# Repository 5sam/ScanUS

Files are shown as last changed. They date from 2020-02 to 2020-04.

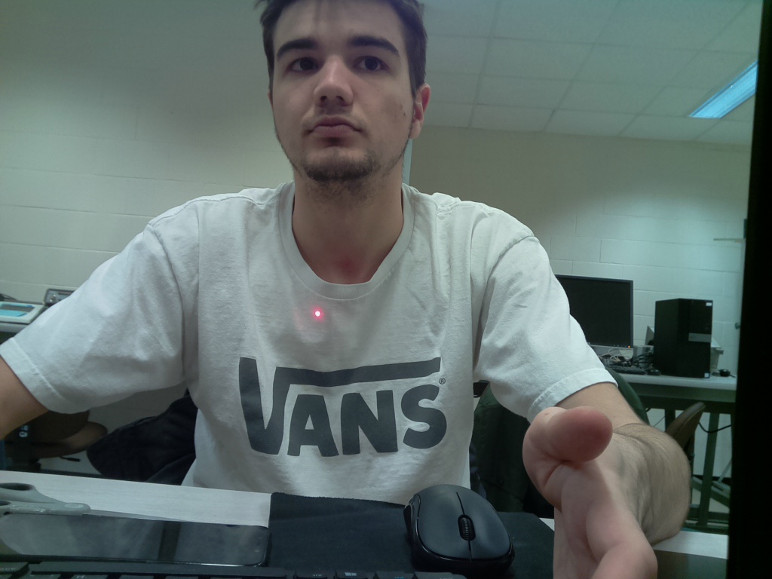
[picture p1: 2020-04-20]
test.jpg

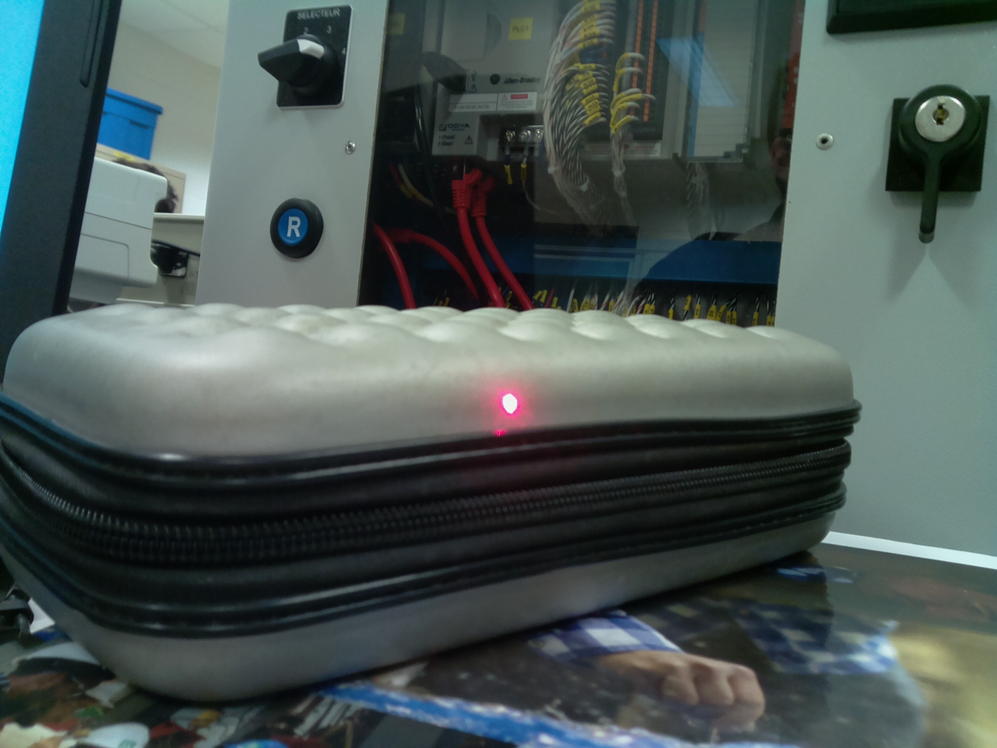
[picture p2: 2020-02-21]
Images/pi_test_proche.jpg

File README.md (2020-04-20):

# ScanUS
4th semester project of Robotics Engineering at **Université de Sherbrooke**

This project is a simple and cheap solution to 3D scanning
## Calibration
### Intrinsic Parameters
- To calibrate the intrinsic parameters of your Picamera, you should take at least 20-30 pictures of a calibration grid
- Chessboard calibration grid patterns can be found [here](https://markhedleyjones.com/projects/calibration-checkerboard-collection)
- The parameters of the chosen grid can be set in the calibration.py header or can be inputs when you call calib_camera()
- The outputed values of **mtx** and **dist** should then be written in the header of camera.py
### Extrinsic Parameters
- To calibrate the extrinsic parameters of the camera, use calib_camera_ext() with a picture containing known positions in world
- Enter known points in points_in_world array
- Locate points in the same order using the zooming option if necessary (using **z** key)
- Double-click to save point
- Once all points are saved press **esc** to exit and plug the output to CAMERA_POS in camera.py if the error is acceptable
- If the error is unacceptable, repeat this process with more known points

### Note
- The camera must have its y axis pointing towards the center of the image when calculating the **CAMERA_POS** and **CAMERA_ANGLES** 

## Setting up the Pi
### Material needed:
- A Raspberry Pi 3B/3B+
- A working internet connection
- A fan

### Note: 
OpenCV is the library that allows the image analysis portion of the software. 
However, installation on the Raspberry Pi as of 2020/02/25 is difficult due to there not being
precompiled binaries in PyPi. 
An Pi image with a compiled version of OpenCV was included to make the installation easier for future users. 
The manual compilation will be explained further bellow. 

### Recommended installation:
1. Download the image of the Pi contained in the [link](currently missing:we did not find a good way to share 32Gb)
2. Install BalenaEtcher to flash the image to your microSD card.
3. All of the libraries used will already be installed. So the installation is now complete.
4. To use the virtual environment. Type the following commands into the terminal:
- source ~/.profile
- workon cv 
5. If you see (cv) on the command line. You are now working on the virtual environment set up to work with openCV. 
6. Head to your project directory and run your code by calling your main:
python file_name.py
7. If done correctly. The libraries should be accessible and the code should run without a hastle.

### Manual installation:
1. Start by opening a terminal.
2. Check if a compiled binary exists by typing:
sudo pip install opencv-contrib-python
If there installation begins. SKIP to step 6.
2. To manually install/compile OpenCV an internet guide will be used with a few changes. Note that any 
version can be installed. The guide installs version 4.0.0 but we installed the lastest version as of today (4.2.0).
3. The guide can be found [here](https://www.pyimagesearch.com/2018/09/26/install-opencv-4-on-your-raspberry-pi/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)
4. First change to be aware of. make -j4 command should be used as stated in the guide. Be careful, our Pi
3B+ managed to overheat during the installation despite having a heatsink. If you have a fan, make it blow air 
towards your Pi to keep it cool. It is possible for your Pi to shutdown or throttle if it is not cooled properly 
slowing down the installation. Despite the installation working well. Your Pi may hang due to a race condition 
towards the end. If so, press ctrl+C to terminate compilation (ours did around 80% and then around 98%). 
Don't worry, the files that are already compiled will not be compiled again. Then modify the command to: 
make -j1 
The compilation will be slower but will no longer hang indefinately in the critical sections. 
5. In step 6, make sure to browse your Pi's directory for the files mentionned. Your 
cv2.cpython-35m-arm-linux-gnueabihf.so and cv2.so files might be in different folders depending on your python
version and location of your python files inside your Pi. Search for them through your files and use the correct 
path to avoir errors in creating the link to your virtual environment.
6. With your environment set up. Open a terminal and call the following 2 commands:
source ~/.profile
workon cv
The first one allows you to use workon cv command to open the virtual environment set up with openCV in the current 
terminal. The second is the activation of the environment.
7. Many external libraries are used with this project. The following steps are necessary if they haven't yet been 
installed on your Pi. 
8. Open a terminal and open your virtual environment.
9. Go to your project's path and run the main with:
python main.py
10. If you get a message saying an import could not be found. Type the name of the library on google as follows:
"library_name pypi"
PyPI contains all the libraries used and will show the correct pip install command to download the latest version of
each library.

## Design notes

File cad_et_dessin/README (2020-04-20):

Bill of matérial are in the drawing of assembly of Full_model.
Model of standard part are found the on site of McMaster.
Counsult https://www.mcmaster.com/ for more information.

Assembly note :
Cad of the XM430-W350-R.step is used as standin for the XM430-W350-T and the XL430-W240-T. 
The XL430-W240-T is place at the base of the Rail. (see Lazer_stand.sldasm)
Full_model depict reasonnable distance for the laser and camera, adjust position on the base and in the code if needed.
Fix your open cr and Pi on the base if needed.
Verifie the  flange on your motor and adjust the configuration of connector if needed.
Laser_stand and turning_table may be placed on any surface, but we recommande fixing it to sheet of plywood 3/4

## 3D Printer Settings
  Each part was printed on a Creality Ender 3 and had different settings depending on the part.
  The software used to slice the parts is Ultimaker Cura 4.5 and prints were all made on standard quality.
  All supports are generated with the default overhang angle calculation from the software and all other settings
  are the ones by default.
  ### Mobile support
  - 20% infills
  - No Supports
  - Extruder temp: 200
  - Bed temp: 55
  ### Turntable Support
  - 20% infill
  - Supports on
  - Extruder temp: 200
  - Bed temp: 55
  ### Wheels
  - 20% infill
  - No Supports
  - Extruder temp: 200
  - Bed temp: 55
  ### Spacers
  - 50% infill
  - No Supports
  - Extruder temp: 200
  - Bed temp: 55
  ### Rail
  - 65% infill
  - Supports On
  - Extruder temp: 200
  - Bed temp: 55
  ### Connector Bolt
  - 35% infill
  - Supports On
  - Extruder temp: 200
  - Bed temp: 55
  - Bed plate adhesion: Brim (to reduce warping)
  ### Connector Motor
  - 35% infill
  - Supports On
  - Extruder temp: 200
  - Bed temp: 55
  - Bed plate adhesion: Brim (to reduce warping)
© 2020 GitHub, Inc.

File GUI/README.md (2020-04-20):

# gui.py
Contains the class Application used to generate the UI **Université de Sherbrooke**

## Code
### Common usage
- import tkinter as tk
- create an instance of tk.Tk() i.e.: your_instance=tk.Tk()
- Optionally, give the window a name using: your_instance.title('Your_title') 
- Create an instance of the user interface with gui_instance = gui.Application(master=your_instance)
## Functions

# def __init__(self, master=none):
- Constructor to create window and buttons for the gui
- Creates thread safe objets that are to be shares with other sections of code outside of UI
- Creates the thread to handle the window events

# def create_widgets(self, need_plot):
- Creates the different buttons including their positions and actions when pressed
- Receives the variable to be toggled by the checkbox 

# def set_running(self, value): 
- sets value of is_running to value using the lock to prevent issue with threads

# def get_running(self):
- returns value of is_running using the lock to prevent issue with threads

# def set_cancel(self, value):
- sets value of cancel to value using the lock to prevent issue with threads

# def get_cancel(self):
- returns value of canel using the lock to prevent issue with threads

# def get_need_plot(self):
- returns value of need plot using the lock to prevent issue with threads

# def toggle_var_plot(self):
- Changes value of plot from False to True according to it's previous value using the lock to prevent issues with threads

# def do_stop(self):
- Called by stop button
- Deactivates the stop button and activates the buttons start and cancel
- Sets is_running to false

# def do_start(self):
- Called by start button
- Deactivates the start button and activates the buttons stop and cancel
- Sets is_running to true and cancel to false 

# def do_cancel(self):
- Called by cancel button
- Deactivates the buttons cancel and stop (if necessary) and activates the start button
- Sets cancel to true

# def plot_change(self):
- Called when clicking the checkbox
- Toggles need_plot to the correct value according to the checkbox

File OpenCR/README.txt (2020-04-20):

- Follow the steps in this guide to properly set up your OpenCr:
	http://emanual.robotis.com/docs/en/software/dynamixel/dynamixel_workbench/

-Change the DXL_IDs in communication.ino to fit your motor, you can find them by using one of the tutorial's function
in the previously downloaded library called <Find>.

-Upload communication.ino on your OpenCr.

-Plug 2 motors directly into the Opencr (1 XM,it is going to be motor 1 and 1 XL, it is going to be motor 2) and one motor in serial with one that is plug into the OpenCr (motor 3)

-Connect your OpenCr with a Pi or a computer by a serial port.

-run a code with motor.py to make a motor run, stop, go to a position or to get its angle.

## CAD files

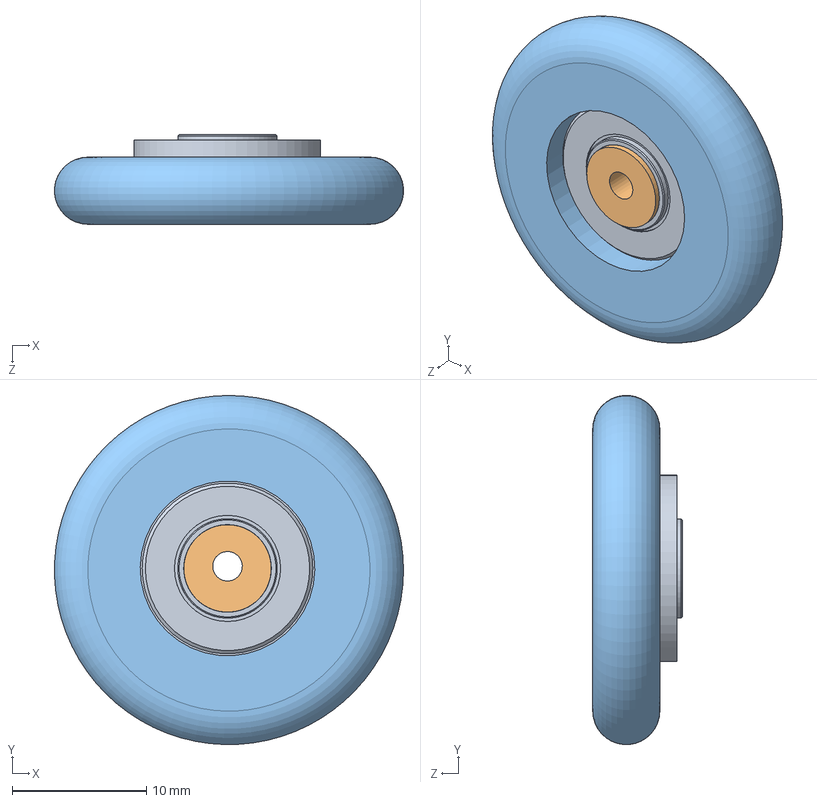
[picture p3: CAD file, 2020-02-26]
cad_et_dessin/cad et dessin/assemblage base plaque/assemblage_roue.SLDASM
26.0 x 26.0 x 6.67 mm
57155K337_STAINLESS STEEL BALL BEARING
spacer
wheel

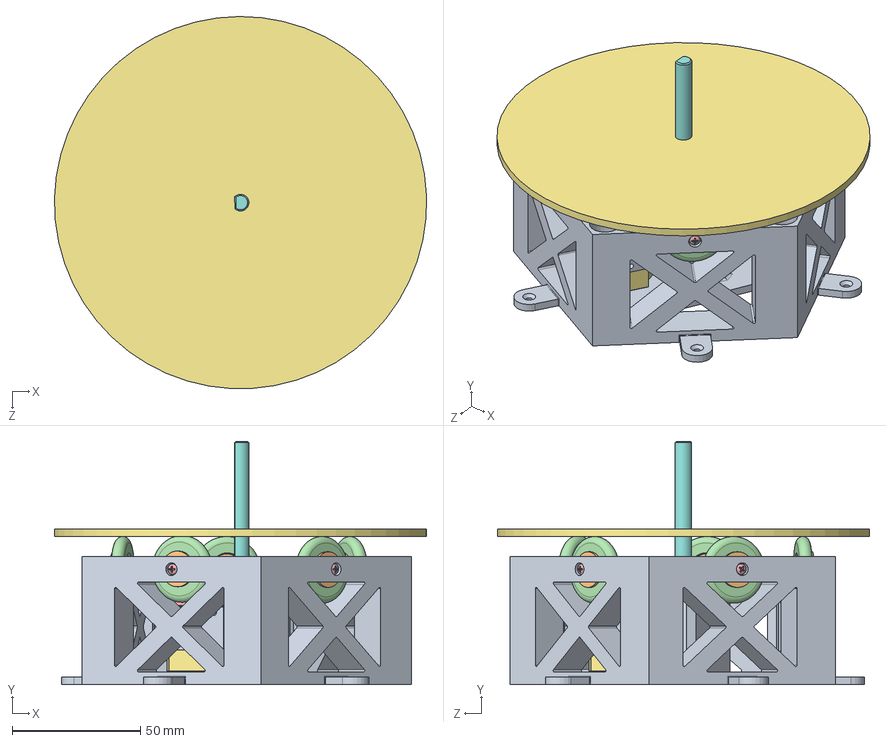
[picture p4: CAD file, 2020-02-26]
cad_et_dessin/cad et dessin/assemblage base plaque/assemblague_base_moteur.SLDASM
144.9 x 94.8 x 144.9 mm
pentagonemagique
Part 1.step
Part 2.step
Part 3.step
Part 4.step
Part 5.step
Part 6.step
Part 7.step
Part 8.step
Part 9.step
Part 10.step
Part 11.step
Part 12.step
Part 13.step
Part 14.step
Part 15.step
Part 16.step
57155K337_STAINLESS STEEL BALL BEARING x 5
spacer x 5
wheel x 5
91802A084_STAINLESS STEEL PHILLIPS OVAL HEAD SCREWS x 5
90480A003_LOW-STRENGTH STEEL HEX NUT x 5
plaque_tournante_2
D_shaft

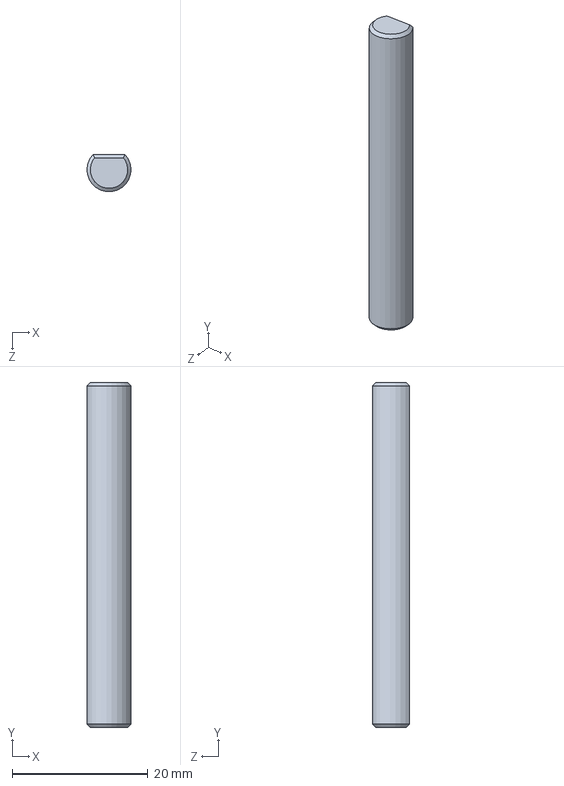
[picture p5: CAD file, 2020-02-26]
cad_et_dessin/cad et dessin/D_shaft.SLDPRT
6.49 x 50.8 x 5.47 mm

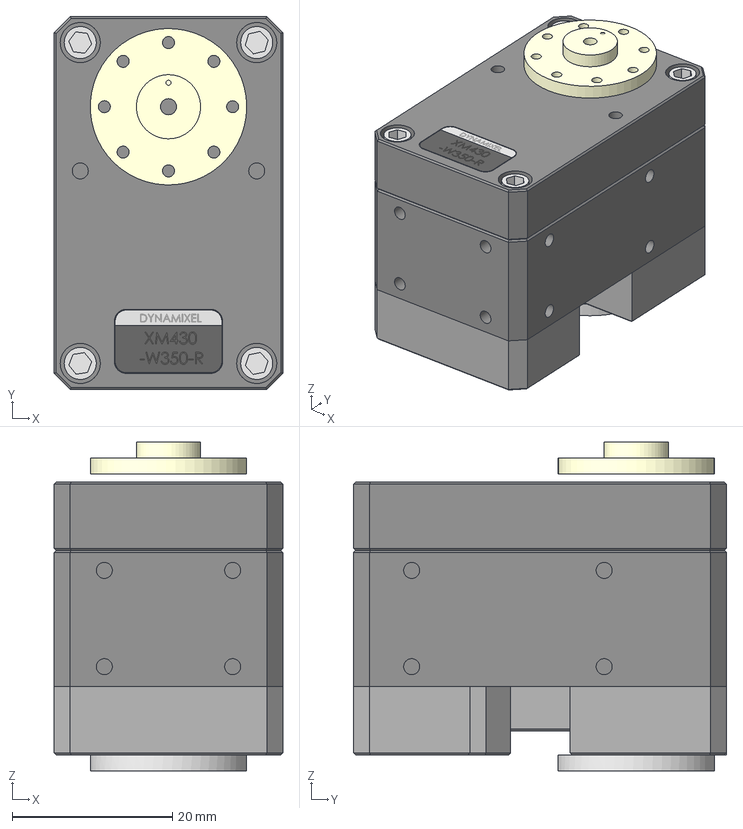
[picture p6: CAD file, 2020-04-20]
cad_et_dessin/XM430-W350-R/dynamixel-xm430-w350-r-1.snapshot.6/XM430-W350-R.step
28.5 x 46.5 x 41.0 mm

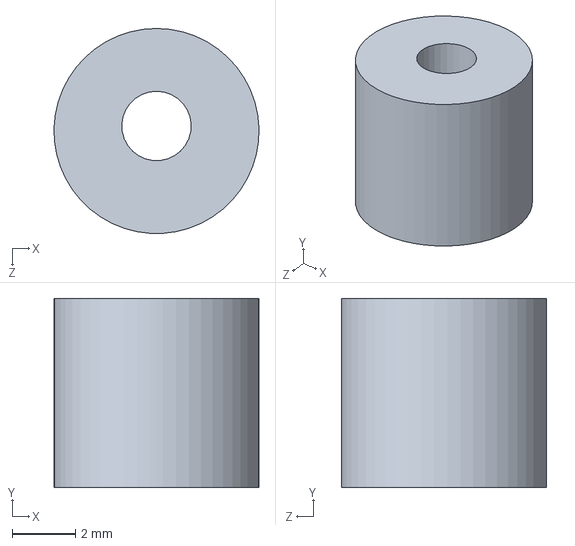
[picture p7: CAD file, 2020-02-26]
cad_et_dessin/cad et dessin/assemblage base plaque/spacer.SLDPRT
6.50 x 6.00 x 6.50 mm

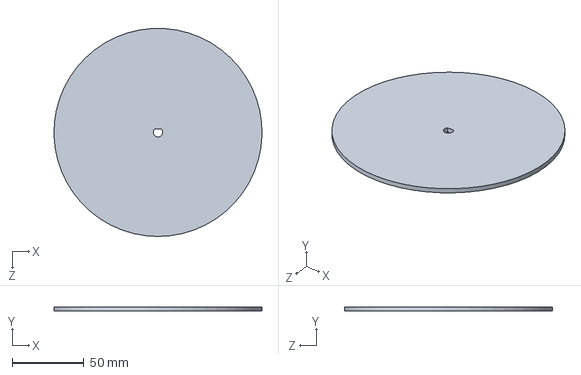
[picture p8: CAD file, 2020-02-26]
cad_et_dessin/cad et dessin/plaque_tournante_2.SLDPRT
144.9 x 3.00 x 144.9 mm

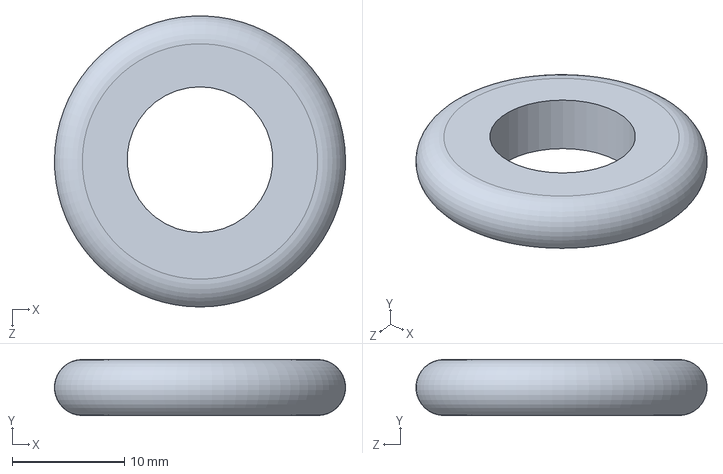
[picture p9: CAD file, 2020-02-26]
cad_et_dessin/cad et dessin/assemblage base plaque/wheel.SLDPRT
26.0 x 5.00 x 26.0 mm

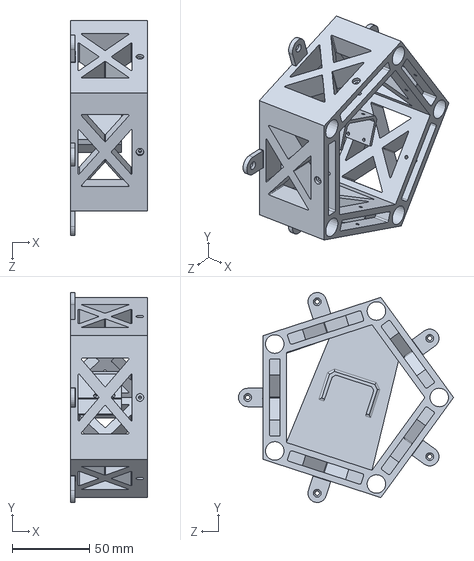
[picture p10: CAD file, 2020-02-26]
cad_et_dessin/cad et dessin/assemblage base plaque/pentagonemagique.SLDPRT
50.0 x 135.6 x 139.0 mm

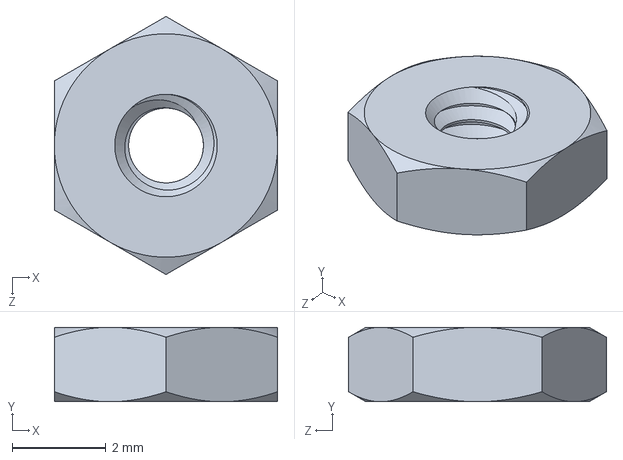
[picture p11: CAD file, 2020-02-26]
cad_et_dessin/cad et dessin/assemblage base plaque/90480A003_LOW-STRENGTH STEEL HEX NUT.SLDPRT
4.76 x 1.59 x 5.50 mm

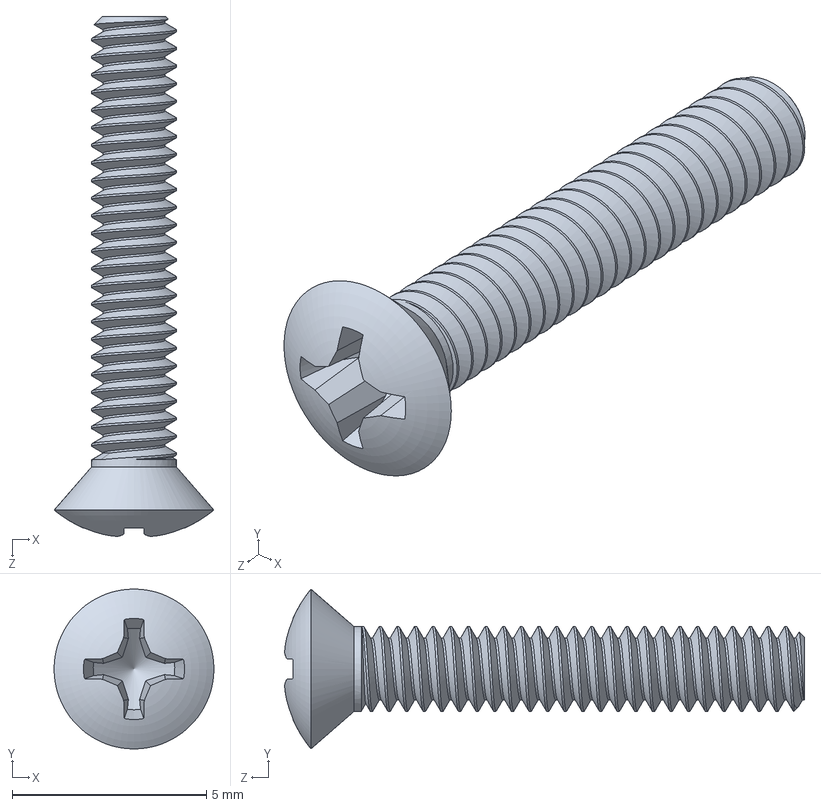
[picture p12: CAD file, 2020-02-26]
cad_et_dessin/cad et dessin/assemblage base plaque/91802A081_STAINLESS STEEL PHILLIPS OVAL HEAD SCREWS.SLDPRT
4.11 x 4.11 x 13.4 mm

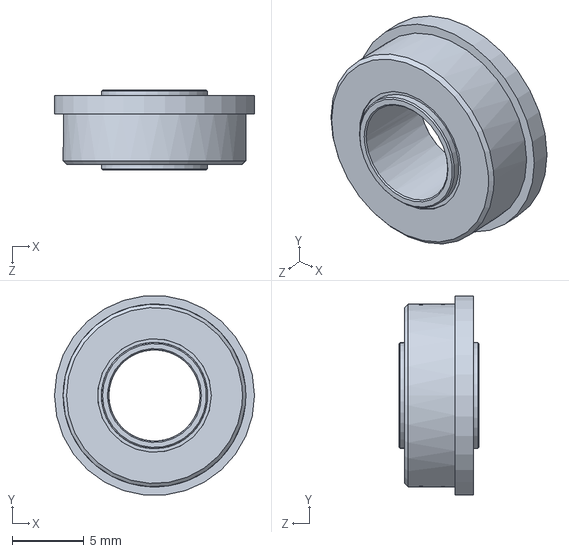
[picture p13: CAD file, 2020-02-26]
cad_et_dessin/cad et dessin/assemblage base plaque/57155K337_STAINLESS STEEL BALL BEARING.SLDPRT
13.9 x 13.8 x 5.56 mm

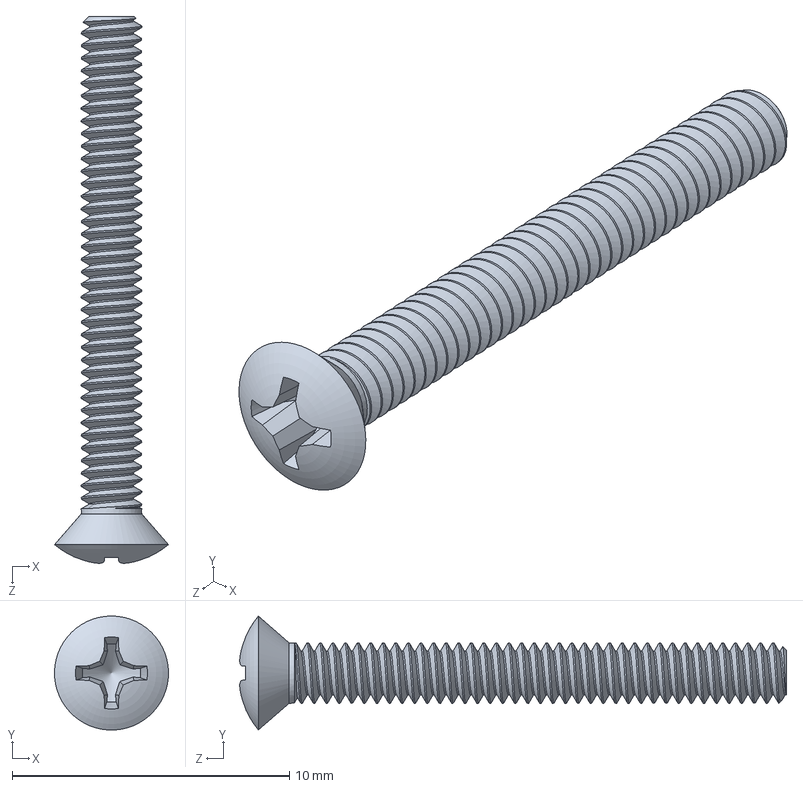
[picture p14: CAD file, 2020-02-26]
cad_et_dessin/cad et dessin/assemblage base plaque/91802A084_STAINLESS STEEL PHILLIPS OVAL HEAD SCREWS.SLDPRT
4.11 x 4.11 x 19.7 mm

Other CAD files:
cad_et_dessin/XM430-W350-R/dynamixel-xm430-w350-r-1.snapshot.6/XM430-W350-R.stl
cad_et_dessin/XM430-W350-R/dynamixel-xm430-w350-r-1.snapshot.6/XM430-W350-R.x_t
cad_et_dessin/cad et dessin/assemblague_base_moteur.SLDDRW

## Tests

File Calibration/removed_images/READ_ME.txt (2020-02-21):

In this folder are images where the findchessboardcorners function found a board but was unprecise
those images where removed to boost calibration accuracy:

10 18 22 37 38

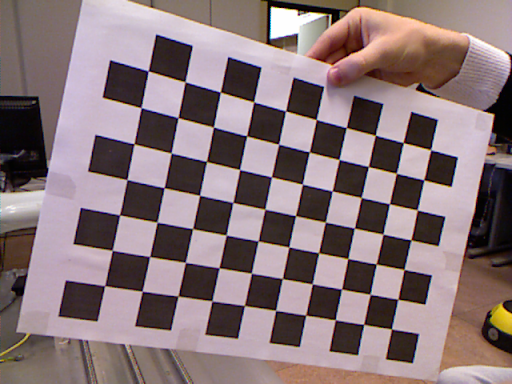
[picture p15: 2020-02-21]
Images/test_calib.png

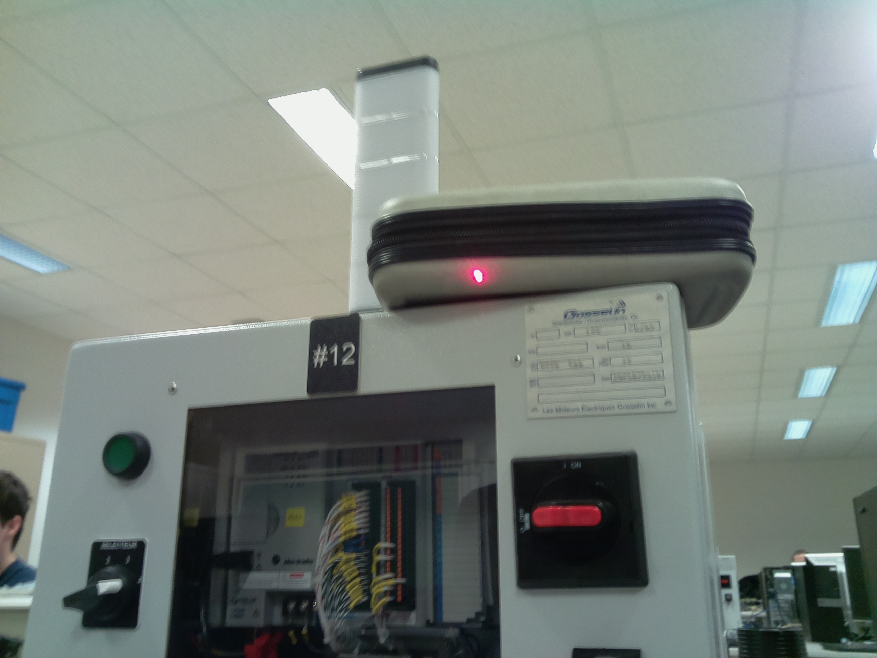
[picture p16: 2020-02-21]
Images/pi_test_loin.jpg

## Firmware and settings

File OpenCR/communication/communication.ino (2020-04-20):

/*******************************************************************************
* Copyright 2016 ROBOTIS CO., LTD.
*
* Licensed under the Apache License, Version 2.0 (the "License");
* you may not use this file except in compliance with the License.
* You may obtain a copy of the License at
*
*     http://www.apache.org/licenses/LICENSE-2.0
*
* Unless required by applicable law or agreed to in writing, software
* distributed under the License is distributed on an "AS IS" BASIS,
* WITHOUT WARRANTIES OR CONDITIONS OF ANY KIND, either express or implied.
* See the License for the specific language governing permissions and
* limitations under the License.
*******************************************************************************/

/* Authors: Taehun Lim (Darby) */

#include <DynamixelWorkbench.h>

#if defined(__OPENCM904__)
  #define DEVICE_NAME "3" //Dynamixel on Serial3(USART3)  <-OpenCM 485EXP
#elif defined(__OPENCR__)
  #define DEVICE_NAME ""
#endif   

//DXL_ID1 motor id for the rotative scoop (XM) 101
//DXL_ID2 motor id for the endless screw (XL) 224
//DXL_ID3 motor id for the laser (XM) 110
#define NOMBRE_TIC 4096
#define BAUDRATE   57600
#define DXL_ID1    101
#define DXL_ID2    224
#define DXL_ID3    110
//to set up the laser ON and OFF
#define laser_pin 4 // pin 4 on board
#define laser_5V  6 // pin 6 on board

DynamixelWorkbench dxl_wb;

//initiate and test if the designated motor respond
void init_motor(int motor)
{
  uint16_t model_number = 0;
  const char *log;
  bool result = false;
  result = dxl_wb.init(DEVICE_NAME, BAUDRATE, &log);
  if (result == false)
  {
    Serial.println(log);
    Serial.println("Failed to init");
  }
  else
  {
    Serial.print("Succeeded to init : ");
    Serial.println(BAUDRATE);
  }

  result = dxl_wb.ping(motor, &model_number, &log);
  if (result == false)
  {
    Serial.println(log);
    Serial.println("Failed to ping");
  }
  else
  {
    Serial.println("Succeeded to ping");
    Serial.print("id : ");
    Serial.print(motor);
    Serial.print(" model_number : ");
    Serial.println(model_number);
  }
  result = dxl_wb.wheelMode(motor, 0, &log);
  if (result == false)
  {
    Serial.println(log);
    Serial.println("Failed to change wheel mode");
  }
  else
  {
    Serial.println("Succeed to change wheel mode");
  }
}

//convert a string to an int
int motor_number_to_int(String motor_number)
{
  if (motor_number == "1"){
    return DXL_ID1;
  }
  if (motor_number == "2"){
    return DXL_ID2;
  }
  if (motor_number == "3"){
    return DXL_ID3;
  }
  else {
    Serial.println("wrong motor number input");
    return -1;
  }
}

//convert a string to an int
int motor_command_to_int(String motor_command)
{
  if (motor_command == "start"){
    return 1;
  }
  if (motor_command == "stop"){
    return 2;
  }
  if (motor_command == "restart"){
    return 3;
  }
  if (motor_command == "position"){
    return 4;
  }
  if (motor_command == "level"){
    return 5;
  }
  else {
    return 6;
  }
}

//convert a string to an int
int motor_argument_to_int(String motor_argument)
{
  int argument = motor_argument.toInt();
  return argument;
}

void laser_ON(){
  digitalWrite(laser_pin, HIGH);
}

void laser_OFF(){
 digitalWrite(laser_pin, HIGH);
}

void setup()
{
  Serial.begin(9600);
  // uncomment next line to wait for Opening Serial Monitor
  //while(!Serial);
  uint8_t dxl_id1 = DXL_ID1;
  uint8_t dxl_id2 = DXL_ID2;
  uint8_t dxl_id3 = DXL_ID3;
  init_motor(dxl_id1);
  init_motor(dxl_id2);
  init_motor(dxl_id3);
  pinMode(laser_pin, OUTPUT);
  pinMode(laser_5V, OUTPUT);
  digitalWrite(laser_5V, HIGH);
  laser_OFF();
}

void loop() {
  float angle = 0;
  uint8_t dxl_id1 = DXL_ID1;
  uint8_t dxl_id2 = DXL_ID2;
  uint8_t dxl_id3 = DXL_ID3;
  int32_t Position = 0;
  int32_t Position1 = 0;
  int32_t Position2 = 0;
  int32_t Position3 = 0;
  
  //get the command from serial port
  if (Serial.available() > 0) {
    String command_received = Serial.readString();
    if(command_received != 0){
      //*************************************************************
      int n = command_received.length();
      // declaring character array
      char char_array[n + 1];
      // copying the contents of the
      // string to char array
      strcpy(char_array, command_received.c_str());
      const char s[2] = "-";
      char *token;
      String info_command[3];

      /* get the first token */
      token = strtok(char_array, s);
      info_command[0] = token;
      int command_number = 1;
      /* walk through other tokens */
      while ( token != NULL ) {
         token = strtok(NULL, s);
         info_command[command_number] = token;
         command_number = command_number + 1;
         if (command_number == 3){
           token = NULL;
         }
      }
      //***************************************************************
      String motor_number = info_command[0];
      String motor_command = info_command[1];
      String motor_argument = info_command[2];

      //convert string to int
      int motor_number_int = motor_number_to_int(motor_number);
      int motor_command_int = motor_command_to_int(motor_command);
      int motor_argument_int = motor_argument_to_int(motor_argument);

      switch (motor_command_int) {

        //start
        case 1:
          laser_ON();
          if (motor_argument_int > 500){
             motor_argument_int = 1000 - motor_argument_int;
          }
          dxl_wb.wheelMode(motor_number_int, 0);
          dxl_wb.goalVelocity(motor_number_int, (int32_t)motor_argument_int);
          break;

        //stop
        case 2:
          laser_OFF();
          dxl_wb.wheelMode(motor_number_int, 0);
          dxl_wb.goalVelocity(motor_number_int, (int32_t)0);
          break;

        //restart
        case 3:
          laser_OFF();
          dxl_wb.jointMode(motor_number_int, 0, 0);
          dxl_wb.goalPosition(motor_number_int, (int32_t)0);
          break;

         //go_to_position
        case 4:
          dxl_wb.jointMode(motor_number_int, 0, 0);
          dxl_wb.goalPosition(motor_number_int, (int32_t)motor_argument_int);
          break;

          //level
        case 5:
            dxl_wb.getPresentPositionData(motor_number_int, &Position);
            angle = Position*2*PI/NOMBRE_TIC;
            Serial.println(Position);
            if (angle < motor_argument_int){
              dxl_wb.wheelMode(motor_number_int, 0);
              dxl_wb.goalVelocity(motor_number_int, (int32_t)100);
              while (angle + 0.25 < motor_argument_int){
                dxl_wb.getPresentPositionData(motor_number_int, &Position);
                angle = Position*2*PI/NOMBRE_TIC;
                Serial.println(angle);
              }
              dxl_wb.goalVelocity(motor_number_int, (int32_t)0);
            }
            else {
              dxl_wb.wheelMode(motor_number_int, 0);
              dxl_wb.goalVelocity(motor_number_int, (int32_t)-100);
              while (angle - 0.25 > motor_argument_int){
                dxl_wb.getPresentPositionData(motor_number_int, &Position);
                angle = Position*2*PI/NOMBRE_TIC;
                Serial.println(angle);
              }
              dxl_wb.goalVelocity(motor_number_int, (int32_t)0);
            }
          dxl_wb.goalVelocity(motor_number_int, (int32_t)0);
          break;
          
        case 6:
          Serial.println("wrong motor command");
          break;
      }
    }
  }
  else{
    //send the motor angle through the serial port
    dxl_wb.getPresentPositionData(dxl_id1, &Position1);
    dxl_wb.getPresentPositionData(dxl_id2, &Position2);
    dxl_wb.getPresentPositionData(dxl_id3, &Position3);
    Position1 = Position1%4095;
    Position2 = Position2;
    Position3 = Position3%4095;
    float angle1 = Position1*2*PI/NOMBRE_TIC;
    float angle2 = Position2*2*PI/NOMBRE_TIC;
    float angle3 = Position3*2*PI/NOMBRE_TIC;
    Serial.println(angle1);
    Serial.println(angle2);
    Serial.println(angle3);
    delay(10);
    }
}

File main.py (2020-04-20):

import numpy as np
import time
import camera
import plot
from calibration import calib_camera_int, calib_camera_ext
from transform import intersect, Matrix, mult
import cv2
import math
import motor
import os
import laser
import tkinter as tk
import gui

def main_pi():
    # This code is obsolete
    # This code needs to be changed with functions from laser.py if the actual laser tower is used
    my_plot = plot.Plot(name='main plot', range=[0, 10])
    laser_p = [0, 0, 180]
    with camera.init_picamera() as cam:
        input()
        motor.start_motor()
        temp = 0;
        while (True):
            pic = camera.take_one_picture_pi(cam)
            # print(pic)
            ang = -motor.get_angle_motor()
            x, y = camera.find_red_dot(pic)
            if ang > temp:
                break

            floor_matrix = Matrix(angles=[0, 0, ang])
            cam_matrix = Matrix(pos=laser_p, angles=[0, 0, 0.26])
            result_matrix = mult([floor_matrix, cam_matrix])
            p2 = result_matrix.get_pos()
            v2 = result_matrix.get_vector_in_referential([0, 1, 0])

            p1, v1 = camera.get_red_dot_point_vector_in_world(ang, x, y)

            m, l = intersect(p1, v1, p2, v2)
            point = m + [l]
            my_plot.add_point(point)
            # print(m, l, sep=' ')
            temp = ang
            # k = input()
            # if k == 'q':
            #    break
        motor.restart_motor()
    input()
    my_plot.close()


def main_pc():
    # this code uses pictures taken manualy
    # this is not the correct way to use the code but because of COVID-19, the setup was not obtainable
    folder = 'D:\_Udes\S4\Projet\ScanUS\Photos_boite/'
    files = os.listdir(folder)
    laser_angles = [-5, -3, -2, -1, -0.5, 0, 0.5, 1.5, 2, 3, 4]
    my_plot = plot.Plot(name='main plot', range=[0, 10])

    position_laser_ref_plaque = Matrix(pos=[259, 512, 150])
    angle_laser_cam = 11.1 * 2 * math.pi / 360 + math.atan(259 / 512)
    trans_plaque_to_cam_ref = Matrix(angles=[0, 0, angle_laser_cam])
    position_laser = mult([trans_plaque_to_cam_ref, position_laser_ref_plaque])

    for i in range(len(files)):
        filename = folder + files[i]
        img = cv2.imread(filename)
        x, y, fail = camera.find_red_dot(frame=img)

        if not fail:
            angle_table = ((i * 11.25) % 360) * 2 * math.pi / 360
            angle_laser = laser_angles[i // 32] * 2 * math.pi / 360
            p1, v1 = camera.get_red_dot_point_vector_in_world(angle_table, x, y)
            p2, v2 = laser.get_laser_point_vector_in_world(angle_table=angle_table, angle_wrist=angle_laser)
            p, error = intersect(p1, v1, p2, v2)
            my_plot.add_point(p + [error])

        if i > 11*32:
            break

    input()
    my_plot.close()


if __name__ == "__main__":
    #
    #main_pc()
    calib_camera_ext('D:\_Udes\S4\Projet\ScanUS\Calibration\Positions\92400939_675701339671843_4756966280806793216_n.png')
    #calib_camera_int()

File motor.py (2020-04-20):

import serial as serial
import time

# We need roughly 1.2 seconds between 2 different commands, except for the get_angle_motor function

# open the serial communication
# line under is for raspberrypi
# COMMUNICATION_PORT = serial.Serial('/dev/ttyACM0', 9600, timeout=.3)
# line under is for PC
try:
    COMMUNICATION_PORT = serial.Serial('COM6', 9600, timeout=.3)
except:
    print('Could not connect to OpenCR')


# motor 1 is for the plate
# motor 2 is for the power screw
# motor 3 is for the laser
# give you back the motor angle of the input motor (1,2 or 3)
def get_angle_motor(motor_number):
    COMMUNICATION_PORT.reset_input_buffer()
    while COMMUNICATION_PORT.inWaiting() == 0:
        time.sleep(0.001)
    angle_serial1 = COMMUNICATION_PORT.readline()
    while COMMUNICATION_PORT.inWaiting() == 0:
        time.sleep(0.001)
    angle_serial2 = COMMUNICATION_PORT.readline()
    while COMMUNICATION_PORT.inWaiting() == 0:
        time.sleep(0.001)
    angle_serial3 = COMMUNICATION_PORT.readline()

    angle_rad1 = float(angle_serial1)
    angle_rad2 = float(angle_serial2)
    angle_rad3 = float(angle_serial3)

    if motor_number == 1:
        return angle_rad1
    if motor_number == 2:
        return angle_rad2
    if motor_number == 3:
        return angle_rad3


# start the motor at designated speed, speed must be between 0 and 265, input normal or reverse for sens
# example: start_motor(1,200,"reverse")
def start_motor(motor_number, speed = '10', sens = 'normal'):
    if sens == "reverse":
        speed = speed + 1000
    bytenumber = str(motor_number) + "-start-" + str(speed) + "\n"
    COMMUNICATION_PORT.write(bytes(bytenumber, 'utf-8'))


# stop the motor
def stop_motor(motor_number):
    bytenumber = str(motor_number) + "-stop-" + "0" + "\n"
    COMMUNICATION_PORT.write(bytes(bytenumber, 'utf-8'))


# make the motor go to input angle (in radian from 0 to 6.28)
def position_motor(motor_number, angle):
    number = int(angle/2/3.1416*4096)
    bytenumber = str(motor_number) + "-position-" + str(number) + "\n"
    COMMUNICATION_PORT.write(bytes(bytenumber, 'utf-8'))


# go to angle, 0 is the lowest, function used on the screw motor.
# level_motor(4*pi) would result in 2 complete rotation, afterwise
# level_motor(2*pi) would result in 1 complete rotation in the other sens.
def level_motor(angle):
    bytenumber = "2-level-" + str(angle) + "\n"
    COMMUNICATION_PORT.write(bytes(bytenumber, 'utf-8'))

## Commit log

2020-02-15 math camera laser intersect
2020-02-19 close camera ressource to fix bug with cam
    [camera.py]
2020-02-25 Add LICENSE.txt
    Sam m'a dit de venir ici.
2020-02-25 Ubdate LICENSE.txt
    J'ai pas fait confiance à Santiago d’envoyé son lien rapidement.
2020-02-26 Common usage README
    utilisé pycharm pour que le readme soit bien formater
2020-02-26 Create Cad and drawing
2020-02-26 motor doc
2020-03-05 integration camera pi code
2020-03-06 fixation parametre camera dans init
    [camera.py]
2020-03-06 plot thread
2020-03-08 much better plot
    plot is now a class so multiple instances can be used in parrallel. also added color for error
    [main.py, plot.py]
2020-03-11 ajout code pour gerer le laser
2020-03-13 On my way to 3 motors
2020-03-31 3 motors base function
2020-04-16 3 motors all set
2020-04-17 reverse command on speed
    [communication.ino, motor.py]
2020-04-20 Full Model
    Full Model of the projet by 2020-04-20. The motor is removed from the model to be under 25MB. This model can be found in the older cad et dessin folder
2020-04-20 Create Discalmer
    Disclamer for the cad of the motor
2020-04-20 Upload XM430-W350-R motor
    [XM430-W350-R.step, XM430-W350-R.stl, XM430-W350-R.x_t]
